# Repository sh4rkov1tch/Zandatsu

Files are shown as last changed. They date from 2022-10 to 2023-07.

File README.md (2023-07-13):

# Zandatsu Fighting Controller v1.3

# Introduction
As my first electronics project and as a fighting game player, I've decided to build this controller.
It's a small Mixbox-style controller running with an RP2040-Zero and GP2040CE at its core.
It is using MX-Style switches and Kailh hotswap sockets.

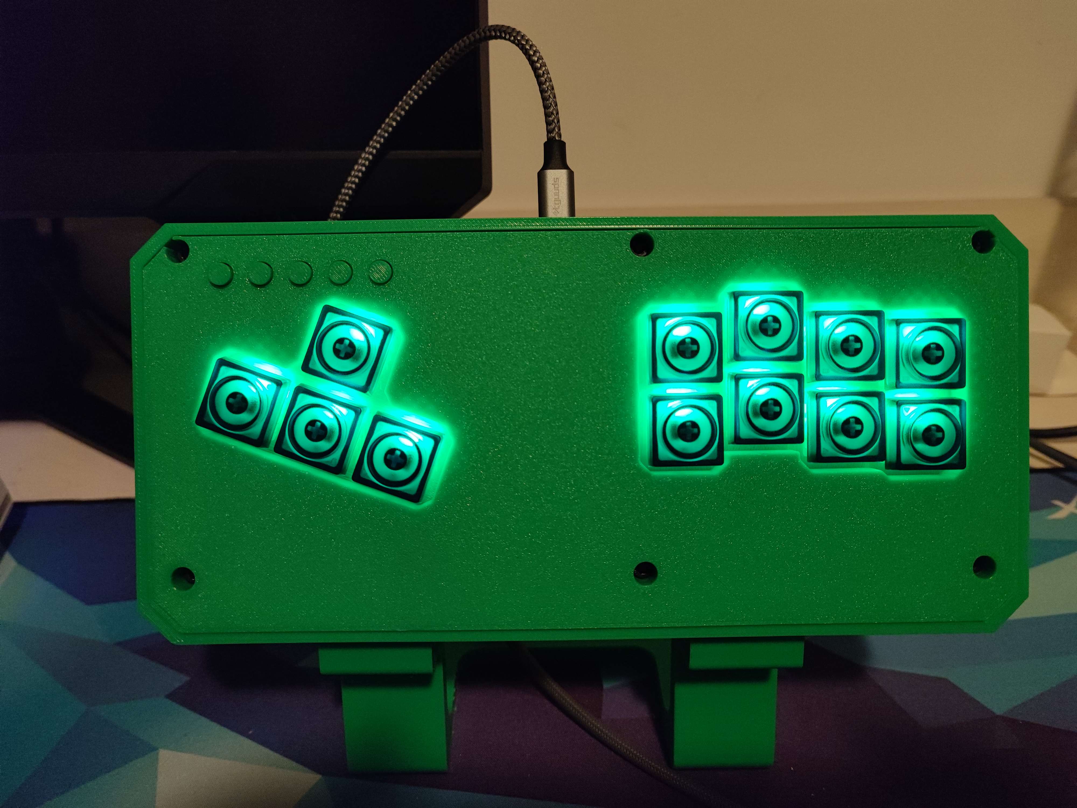
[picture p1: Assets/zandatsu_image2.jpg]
Preview


# Credits
- FeralAI and sleepunit for the awesome GP2040 firmware and the help they gave me through this project
- My electronics and physics professor
- Guydog because I wouldn't even have known that the OpenStick Discord server and GP2040 existed without him
- The OpenStick Community because they made awesome upgrades to GP2040-CE and they also helped me through this project

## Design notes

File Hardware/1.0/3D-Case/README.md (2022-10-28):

# 3D Case
The case was made using OpenSCAD, but I'll also provide the STL files in case you want to print the case only.

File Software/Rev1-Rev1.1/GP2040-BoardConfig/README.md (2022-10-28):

# GP2040 Configuration for Zandatsu
So here's the Zandatsu's boardconfig

## Button Mapping

| Button 	| Pin 	|
|---	|-----	|
| Up 	| 2 	|
| Down 	| 3 	|
| Left 	| 4 	|
| Right  	| 5 	|
| B3 	| 6 	|
| B4 	| 7 	|
| R2 	| 8 	|
| L2 	| 9 	|
| B1 	| 10  	|
| B2 	| 11  	|
| R1 	| 12  	|
| L1 	| 13  	|
| S1 	| 17  	|
| S2 	| 20  	|
| A1 	| 16  	|

## LED Settings
LED Pin - `0`
Max Brightness - `100`
LED Layout  - `WASD`
Brightness Steps - `5`
LEDs per Button - `1`

## LED Order

(From left to right)

```
Up > Down > Left > Right > L1 > R1 > B2 > B1 > B3 > B4 > R2 > L2
```

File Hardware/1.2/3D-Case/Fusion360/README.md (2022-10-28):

# Fusion 360 case
This one is better visually and thinner than the older one, and the screws aren't going to be visible because they're now on the back

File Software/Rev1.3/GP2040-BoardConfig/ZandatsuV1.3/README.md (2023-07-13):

## Zandatsu Rev 1.3 Pin Mappings

## Buttons

| Button | Pin |
|---|-----|
| Up |  1  |
|  Down  |  2  |
|  Left  |  3  |
| Right  |  4  |
|  B1/A/Cross | 5 |
|  B2/B/Circle | 6  |
|  R2/RT | 7  |
|  L2/LT  | 8 |
|  B3/X/Square | 9 |
|  B4/Y/Triangle | 10 |
|  R1/RB | 11 |
|  L1/LB | 15 |
| S1/Back/Select  | 13  |
| S2/Start  | 14 |
| A1/Guide/Home| 12 |
| L3/LS | 27 |
| R3/RS | 26 |

## LEDs

LED Pin: 0

|Index|LED|
|-----|---|
|0|Up|
|1|Left|
|2|Down|
|3|Right|
|4|B1|
|5|B2|
|6|R2|
|7|L2|
|8|B3|
|9|B4|
|10|R1|
|11|L1|

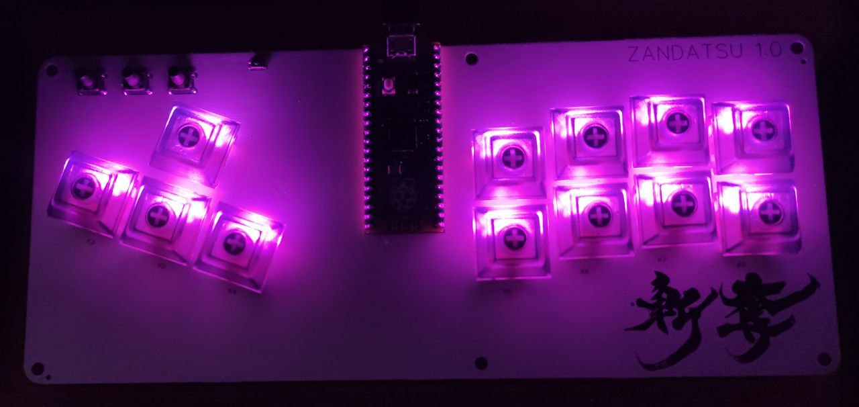
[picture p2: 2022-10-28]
Assets/zandatsu_board.jpg

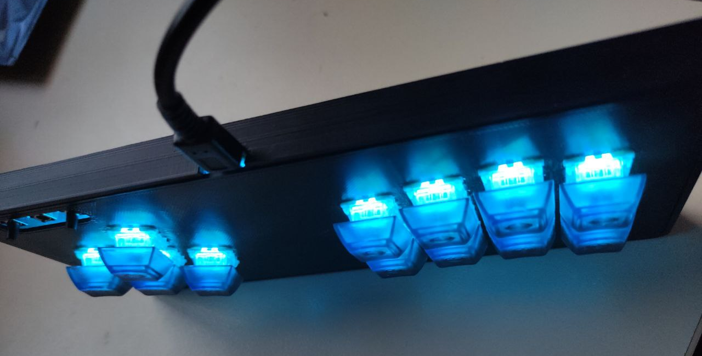
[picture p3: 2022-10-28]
Assets/zandatsu_image1.png

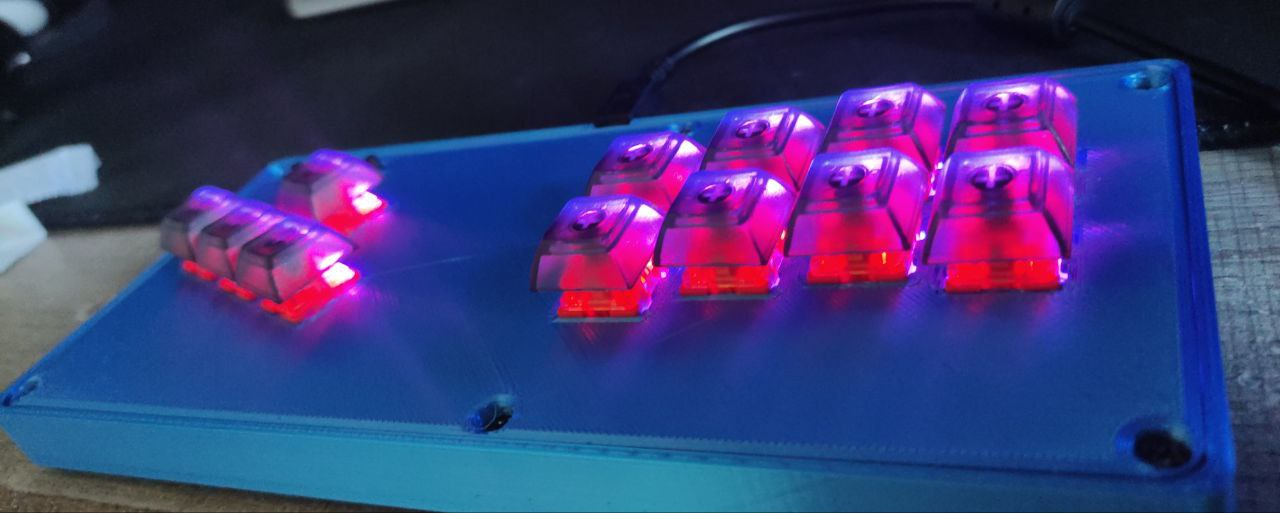
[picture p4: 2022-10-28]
Assets/zandatsu_image0.png

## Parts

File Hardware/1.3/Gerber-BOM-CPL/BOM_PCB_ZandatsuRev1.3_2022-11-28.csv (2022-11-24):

ID | Name | Designator | Footprint | Quantity | Manufacturer Part | Manufacturer | Supplier | Supplier Part | Price
1 | NEOPIXEL_SK6812MINI-E | LED1,LED2,LED3,LED4,LED5,LED6,LED7,LED8,LED9,LED10,LED11,LED12 | SK6812MINI-E_REVERSE-MOUNT | 12 | SK6812MINI-E | null | LCSC | C9900001298
2 | RP2040-Zero | U1 | RP2040-ZERO_SMD_MULTILAYER | 1 |  | Waveshare
3 | TS-1095-A14B3-D1 | SW1,SW2,SW3,SW4,SW5 | SW-TH_4P-L6.0-W6.0-P4.50-LS6.5 | 5 | TS-1095-A14B3-D1 | Yuandi | LCSC | C493021 | 0.045
4 | MXONLY-1U-HOTSWAP | K1,K2,K3,K4,K5,K6,K7,K8,K9,K10,K11,K12 | MXONLY-1U-HOTSWAP | 12

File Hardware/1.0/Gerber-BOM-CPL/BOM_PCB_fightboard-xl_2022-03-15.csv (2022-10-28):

ID | Name | Designator | Footprint | Quantity | Manufacturer Part | Manufacturer | Supplier | Supplier Part | Price
1 | MXONLY-1U-HOTSWAP | K1,K2,K3,K4,K5,K6,K7,K8,K9,K10,K11,K12 | MXONLY-1U-HOTSWAP | 12
2 | TSA061G90-250 | SW13,SW14,SW15 | SW-TH_4P-L6.0-W6.0-P4.50-LS6.5 | 3 | TSA061G90-250 | BRIGHT | LCSC | C294505 | 0.023
3 | TS-1185EC-C-D-B | SW17 | SW-SMD_4P-L3.7-W3.0-P1.50-LS4.7 | 1 | TS-1185EC-C-D-B | XKB Enterprise | LCSC | C318893 | 0.055
4 | RASPBERRY Pi Pico Through Holes | U4 | RASPBERRY PI PICO | 1
5 | WS2812B-2020 | LED1,LED2,LED3,LED4,LED5,LED6,LED7,LED8,LED9,LED10,LED11,LED12 | LED-SMD_4P-L2.0-W2.0-TL_WS2812B-2020 | 12 | WS2812B-2020 | Worldsemi | LCSC | C965555 | 0.156

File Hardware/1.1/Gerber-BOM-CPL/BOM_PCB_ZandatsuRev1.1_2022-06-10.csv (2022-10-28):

ID | Name | Designator | Footprint | Quantity | Manufacturer Part | Manufacturer | Supplier | Supplier Part | Price
1 | RASPBERRY-PI-PICO_TH/SMT (No Debug Pins) | 1 | RASPBERRY-PI-PICO | 1 |  | Raspberry Pi Foundation | Raspberry Pi | RP2040
2 | MXONLY-1U-HOTSWAP | K1,K2,K3,K4,K5,K6,K7,K8,K9,K10,K11,K12 | MXONLY-1U-HOTSWAP | 12
3 | WS2812B-2020 | LED1,LED2,LED3,LED4,LED5,LED6,LED7,LED8,LED9,LED10,LED11,LED12 | LED-SMD_4P-L2.0-W2.0-TL_WS2812B-2020 | 12 | WS2812B-2020 | Worldsemi | LCSC | C965555 | 0.11
4 | TSA061G90-250 | SW13,SW14,SW15 | SW-TH_4P-L6.0-W6.0-P4.50-LS6.5 | 3 | TSA061G90-250 | BRIGHT | LCSC | C294505 | 0.024
5 | TS-1185EC-C-D-B | SW17 | SW-SMD_4P-L3.7-W3.0-P1.50-LS4.7 | 1 | TS-1185EC-C-D-B | XKB Enterprise | LCSC | C318893 | 0.054

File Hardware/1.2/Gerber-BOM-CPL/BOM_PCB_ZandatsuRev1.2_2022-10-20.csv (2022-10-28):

ID | Name | Designator | Footprint | Quantity | Manufacturer Part | Manufacturer | Supplier | Supplier Part | Price
1 | TC-1101DR-9.0H-160 | SW1,SW2,SW3,SW4,SW5 | SW-TH_4P-L6.0-W6.0-P4.50-LS6.5 | 5 | TC-1101DR-9.0H-160 | DEALON(德艺隆) | LCSC | C2905145 | 0.029
2 | RP2040-Zero | U1 | RP2040-ZERO | 1 |  | Waveshare
3 | MXONLY-1U-HOTSWAP | K1,K2,K3,K4,K5,K6,K7,K8,K9,K10,K11,K12 | MXONLY-1U-HOTSWAP | 12
4 | WS2812B-2020 | LED1,LED2,LED3,LED4,LED5,LED6,LED7,LED8,LED9,LED10,LED11,LED12 | LED-SMD_4P-L2.0-W2.0-TL_WS2812B-2020 | 12 | WS2812B-2020 | Worldsemi | LCSC | C965555 | 0.11

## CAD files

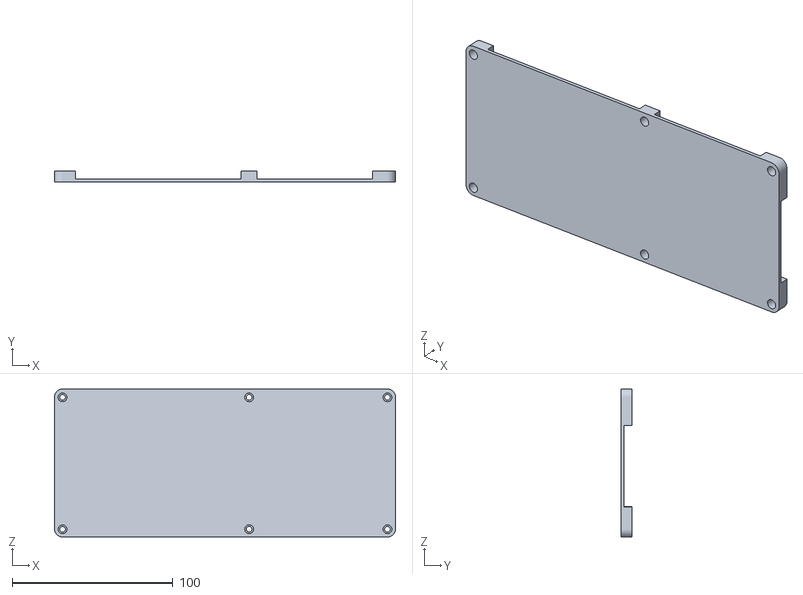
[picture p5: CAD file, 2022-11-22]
Hardware/1.2/3D-Case/Fusion360/zandatsu_back_plate.stl
212.0 x 7.00 x 92.0

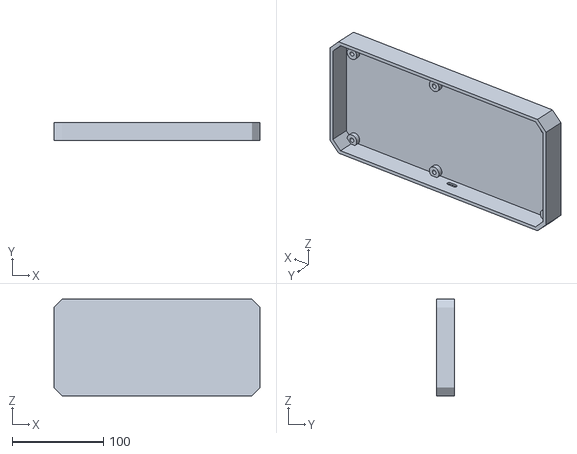
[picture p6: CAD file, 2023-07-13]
Hardware/1.3/3D-Case/STL_Files/case_base.stl
226.0 x 20.0 x 106.0

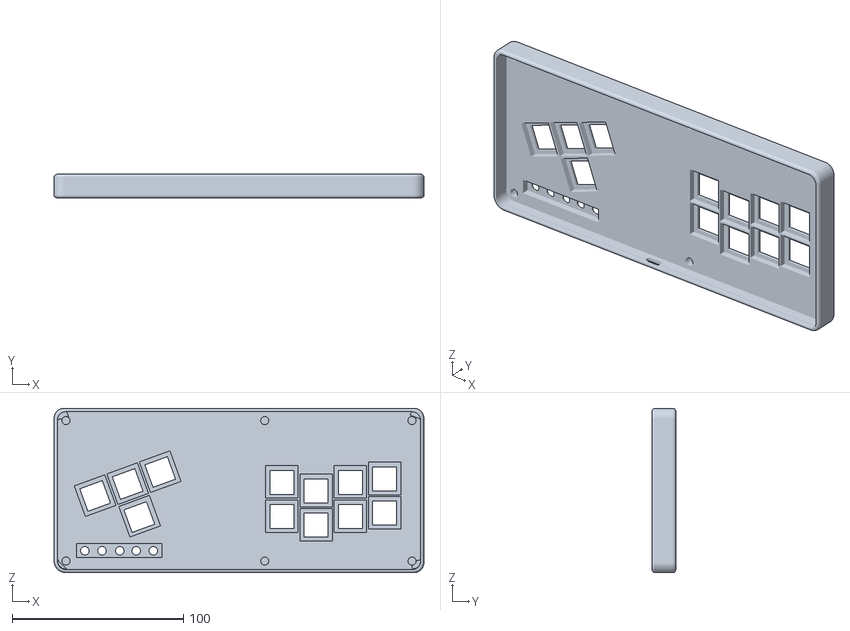
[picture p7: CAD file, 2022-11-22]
Hardware/1.2/3D-Case/Fusion360/zandatsu_front_case.stl
216.0 x 13.8 x 96.0

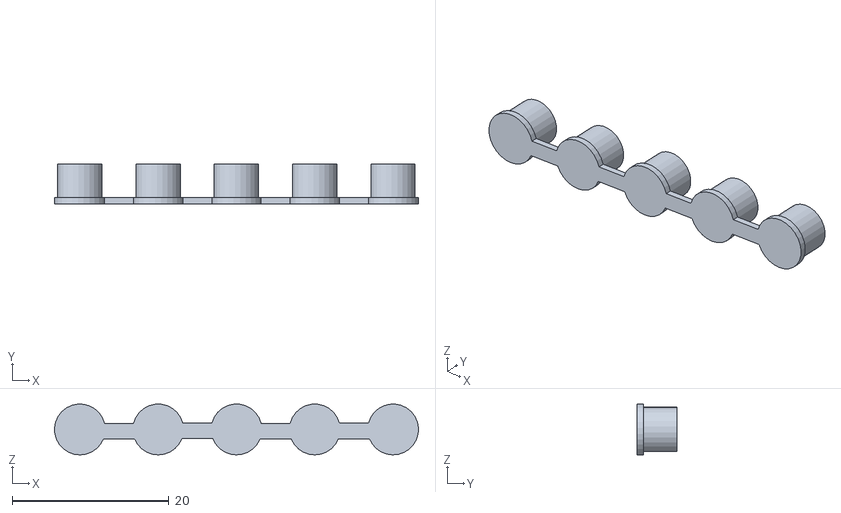
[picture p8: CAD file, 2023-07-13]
Hardware/1.3/3D-Case/STL_Files/buttons.stl
46.5 x 5.10 x 6.49

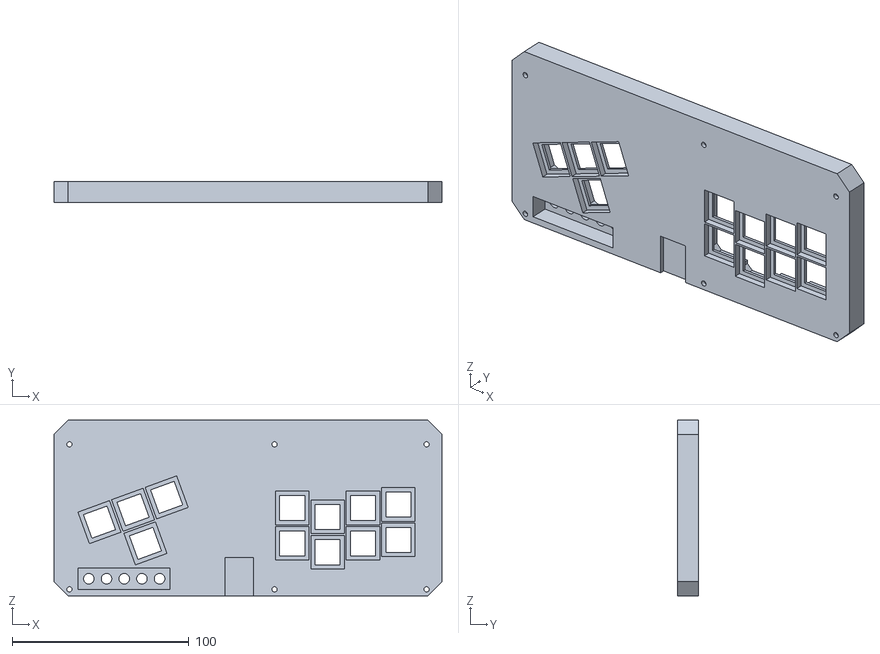
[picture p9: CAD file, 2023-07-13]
Hardware/1.3/3D-Case/STL_Files/frontcase.stl
219.4 x 12.2 x 99.4

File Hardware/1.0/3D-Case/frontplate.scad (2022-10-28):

$fn=75;
szMechanicalSwitch = 14; //Side size

module switchSlot(arrPos, angle=0){
 szMechanicalSwitch = 14.2;
 tabWidth = szMechanicalSwitch+2;
 tabHeight = 3.5;
 
 for(pos = arrPos){
 translate(pos)
  rotate([90, 0, angle]){
   cube(szMechanicalSwitch, center=true);
   translate([0, -6.1, 0])
      cube(19, center=true);
   translate([0, 0, -4.05])
     cube([tabWidth, tabWidth, tabHeight], center=true);
   translate([0, 0, 4.05])
     cube([tabWidth, tabWidth, tabHeight], center=true);
  }
 }
}

module screwSlot(arrPos, diameter=3, wallthickness=2, height=3){
 for(pos = arrPos){
  translate(pos){
   difference(){
    cylinder(h=height, d=diameter+wallthickness, center=true);
    cylinder(h=height+1, d=diameter, center=true);
   }
  }
 } 
}

arrScrewPos = [
 [120, 4, -1.5],
 [120,86, -1.5],
 [206, 4, -1.5],
 [206,86, -1.5],
 [  4, 4, -1.5],
 [  4,86, -1.5]
];


arrWasdPos = [
 [47, 60, 0],
 [21, 48, 0],
 [40, 41, 0],
 [59, 34, 0]
];

posPico = [101, 64, 0];
szPico = [28, 60, 8.5];

arrBtnPos = [
 [127.4, 33.8, 0],
 [127.4, 53.8, 0],
 [147.4, 58.8, 0],
 [147.4, 38.8, 0],
 [167.4, 61.3, 0],
 [167.4, 41.3, 0],
 [187.4, 58.8, 0],
 [187.4, 38.8, 0],
];

arrSecBtnPos = [
 [15.6, 81.7, 0],
 [28.2, 81.5, 0],
 [40.6, 81.4, 0]
];

szSecondaryButtons = 4.4; //Diameter
angleWasd = -20;

roundedCornerDiam = 10;
arrCompRd = [roundedCornerDiam/2, roundedCornerDiam/2];

arrSzPlate = [210-roundedCornerDiam, 90-roundedCornerDiam, 5];

difference(){
 union(){

  translate([roundedCornerDiam/2, roundedCornerDiam/2, 0])
 minkowski(){
  cylinder(d=roundedCornerDiam, h=0.0001, center=false);
  cube(arrSzPlate);
 }
 
}
 
 switchSlot(arrWasdPos, -20);
 switchSlot(arrBtnPos);

 for(secBtnPos = arrSecBtnPos){
   translate(secBtnPos){
    cylinder(d=szSecondaryButtons, h=arrSzPlate.z*2+1 , center=true);
    cube(8, center=true);
   }
}
 
 for(screwPos = arrScrewPos){
    translate(screwPos){
        cylinder(d=3.1, h=arrSzPlate.z*2, center=true);
    }
    translate(screwPos+[0, 0, 5]){
        cylinder(d=6, h=4, center=true);
    }
}
    translate(posPico)
        cube(szPico, center=true);
    translate([61.44, 86.226, 0.5])
        cube([7, 6, 4], center=true);
}
//screwSlot(arrScrewPos, 2.5, 3.5);

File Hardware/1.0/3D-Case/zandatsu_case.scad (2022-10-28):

$fn=70;

iWallThickness = 2;

arrSzPCB = [210, 90, 1.6];
arrBackplaneDiffXY = [iWallThickness*2+1, iWallThickness*2+1, 0];
arrErrorMargin = [1, 1, 1];

iRoundedCornerDiam = 10;
arrRoundedCornerOffset = [iRoundedCornerDiam, iRoundedCornerDiam, 0];

iHeightPylone = 3;
iDiamPylone = 6;
iBackplaneThickness = 3;
iCaseThickness = iBackplaneThickness + 1.6 + 3 +3.6;
arrSzCase = arrSzPCB+arrBackplaneDiffXY-arrRoundedCornerOffset+[0, 0, iCaseThickness];
arrSzHole = arrSzPCB-arrRoundedCornerOffset+arrErrorMargin+[0, 0, iCaseThickness-iBackplaneThickness+0.1];

iUSBHeight = iHeightPylone+1.6+0.5+iBackplaneThickness;
arrUSBSize= [14, 20, 6];


arrScrewPos = [
 [120, 4, -1.5],
 [120,86, -1.5],
 [206, 4, -1.5],
 [206,86, -1.5],
 [  4, 4, -1.5],
 [  4,86, -1.5]
];

arrUSBPos = [arrScrewPos[0].x-19+3, 99,  iUSBHeight];

translate(arrRoundedCornerOffset)
    difference(){
        difference(){
            minkowski(){
             cube(arrSzCase);
             cylinder(h=0.000000001, d=iRoundedCornerDiam);
            }
            translate([0, 0, iBackplaneThickness]+arrBackplaneDiffXY/2-arrErrorMargin/2)
                minkowski(){
                    cube(arrSzHole);
                    cylinder(h=0.000001, d=iRoundedCornerDiam);
                }
        translate(arrUSBPos-arrBackplaneDiffXY+[0, 0, 3])
            cube(arrUSBSize, center=true);
    }
}



for(screwPos = arrScrewPos){
   difference(){
       translate(arrRoundedCornerOffset/2+arrBackplaneDiffXY/2+[0, 0, iBackplaneThickness-0.2]+screwPos+[0, 0, 3])
        minkowski(){
        cylinder(h=iHeightPylone, d=iDiamPylone, center=true);
        cube([iDiamPylone/1.3, iDiamPylone/1.3, 0.01], center=true);
        }
       translate(arrRoundedCornerOffset/2+arrBackplaneDiffXY/2+[0, 0, iBackplaneThickness-0.2]+screwPos+[0, 0, 3])
        cylinder(h=iHeightPylone+0.1, d=iDiamPylone/1.6, center=true);
    }
}

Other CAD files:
Hardware/1.1/3D-Case/frontplate.scad
Hardware/1.2/3D-Case/OpenSCAD/frontplate.scad
Hardware/1.2/3D-Case/OpenSCAD/zandatsu_case.scad
Hardware/1.3/3D-Case/F360_Project/ZandatsuCase_Angular.f3z

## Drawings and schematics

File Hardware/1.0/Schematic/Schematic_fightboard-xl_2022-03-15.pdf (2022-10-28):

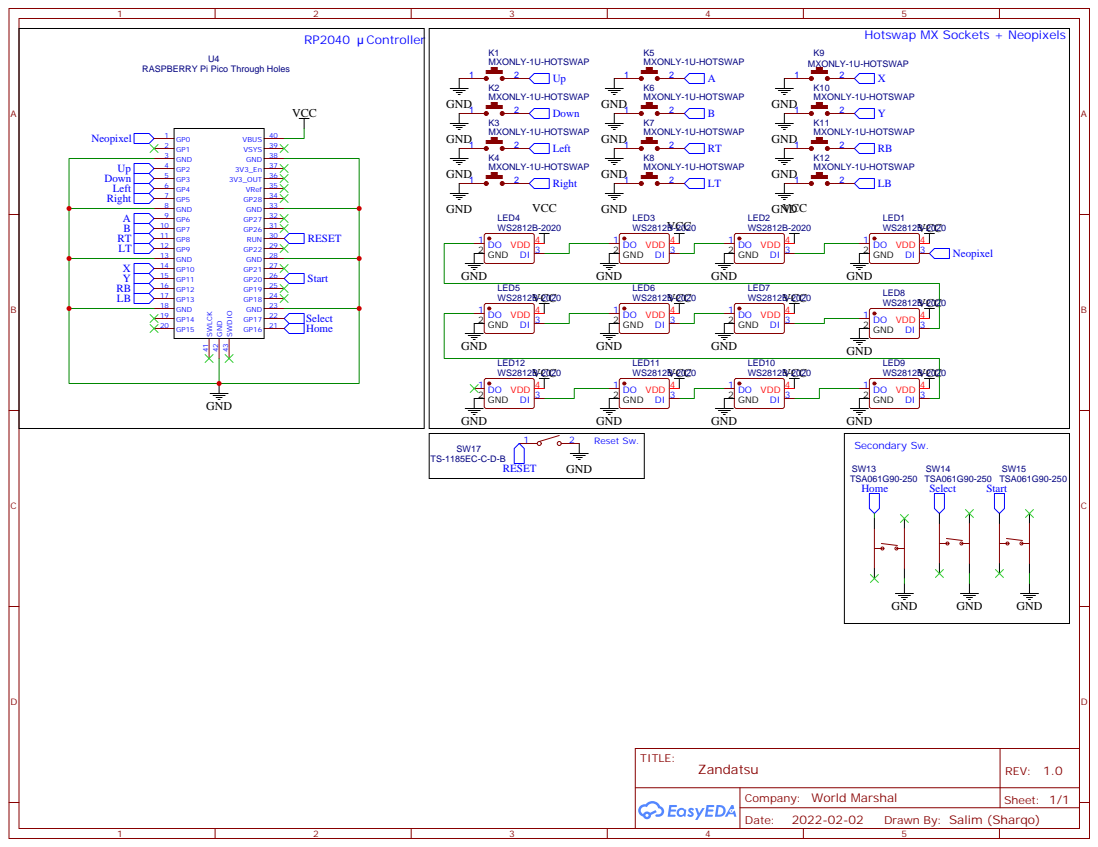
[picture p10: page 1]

RASPBERRY Pi Pico Through Holes

Drawn By: Salim (Sharqo)

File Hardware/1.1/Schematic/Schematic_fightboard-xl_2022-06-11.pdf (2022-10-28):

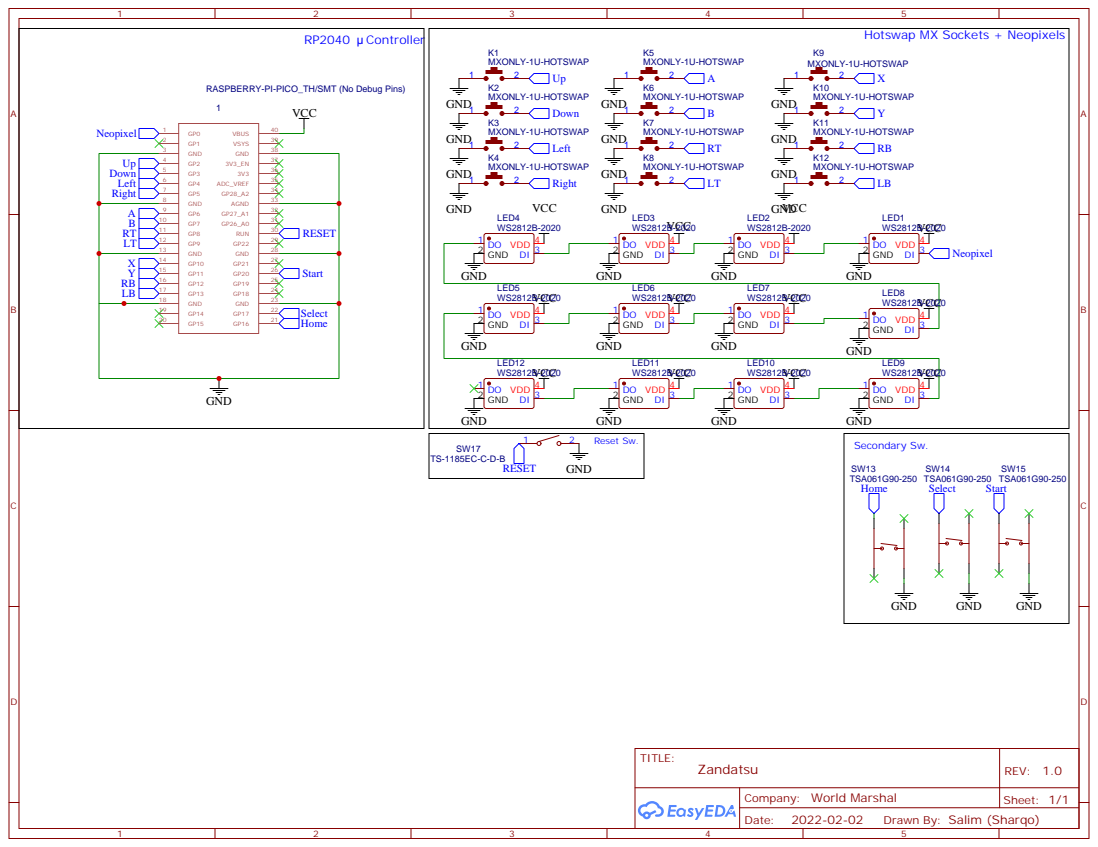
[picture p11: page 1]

RASPBERRY-PI-PICO_TH/SMT (No Debug Pins)

Drawn By: Salim (Sharqo)

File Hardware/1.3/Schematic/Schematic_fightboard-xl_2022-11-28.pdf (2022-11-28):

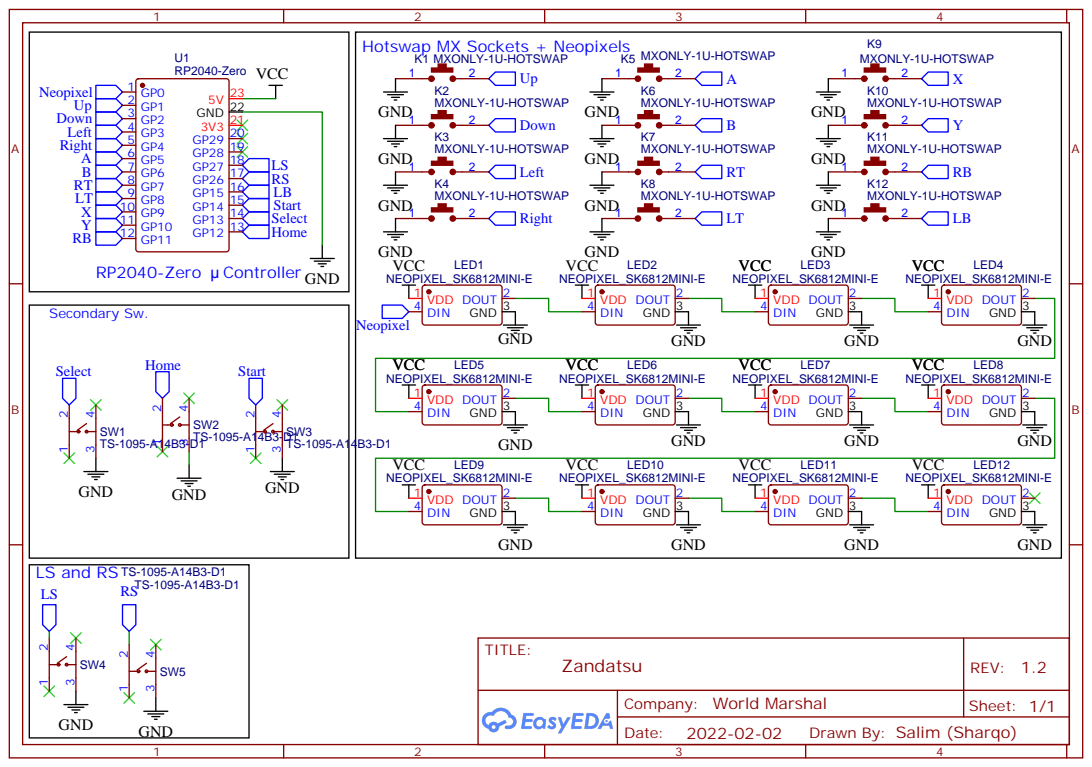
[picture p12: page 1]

Drawn By: Salim (Sharqo)

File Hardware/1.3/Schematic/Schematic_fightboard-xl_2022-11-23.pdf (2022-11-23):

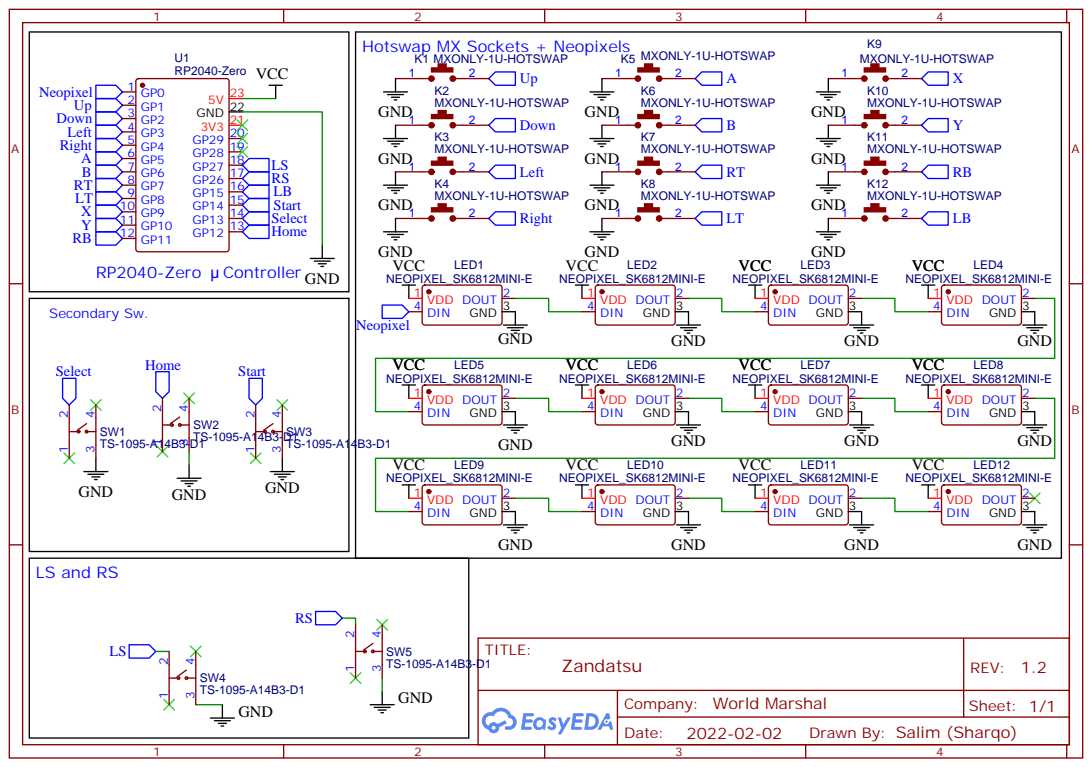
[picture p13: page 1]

Drawn By: Salim (Sharqo)

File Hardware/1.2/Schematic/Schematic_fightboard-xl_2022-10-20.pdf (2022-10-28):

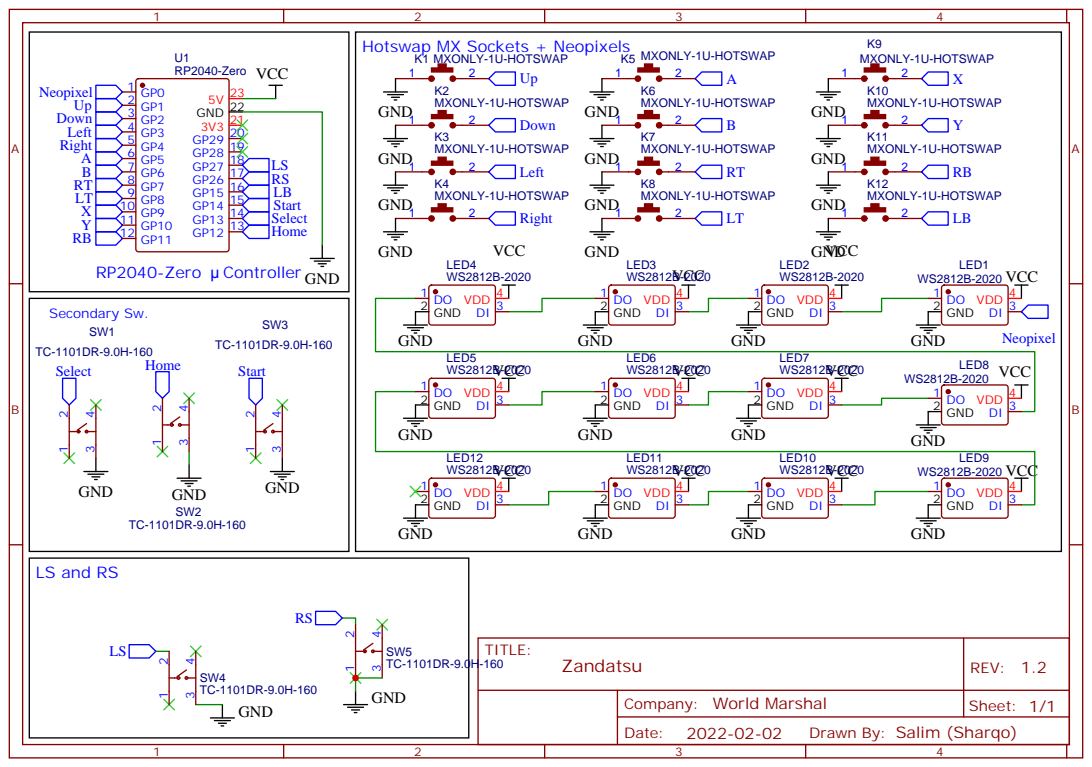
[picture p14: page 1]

Drawn By: Salim (Sharqo)

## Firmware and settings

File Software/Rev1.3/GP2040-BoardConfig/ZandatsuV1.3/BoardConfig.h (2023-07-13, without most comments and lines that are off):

#define PICO_BOARD_CONFIG_H_
#include "enums.pb.h"
#define PIN_DPAD_UP     1           // UP
#define PIN_DPAD_DOWN   2           // DOWN
#define PIN_DPAD_LEFT   3           // LEFT
#define PIN_DPAD_RIGHT  4           // RIGHT
#define PIN_BUTTON_B1   5           // B1 / A / B / Cross / 2 / K1
#define PIN_BUTTON_B2   6           // B2 / B / A / Circle / 3 / K2
#define PIN_BUTTON_R2   7           // R2 / RT / ZR / R2 / 8 / K3
#define PIN_BUTTON_L2   8           // L2 / LT / ZL / L2 / 7 / K4
#define PIN_BUTTON_B3   9          // B3 / X / Y / Square / 1 / P1
#define PIN_BUTTON_B4   10          // B4 / Y / X / Triangle / 4 / P2
#define PIN_BUTTON_R1   11          // R1 / RB / R / R1 / 6 / P3
#define PIN_BUTTON_L1   15          // L1 / LB / L / L1 / 5 / P4
#define PIN_BUTTON_S1   13          // S1 / Back / Minus / Select / 9 / Coin
#define PIN_BUTTON_S2   14					// S2 / Start / Plus / Start / 10 / Start
#define PIN_BUTTON_L3   27          // L3 / LS / LS / L3 / 11 / LS
#define PIN_BUTTON_R3   26          // R3 / RS / RS / R3 / 12 / RS
#define PIN_BUTTON_A1   12          // A1 / Guide / Home / PS / 13 / ~
#define PIN_BUTTON_A2   -1          // A2 / ~ / Capture / ~ / 14 / ~
#define PIN_BUTTON_FN   -1          // Hotkey Function
#define PIN_BUTTON_TURBO -1         // Turbo
#define PIN_BUTTON_REVERSE -1       // UDLR Reverse
#define PIN_SLIDER_LS    -1         // Left Stick Slider
#define PIN_SLIDER_RS    -1         // Right Stick Slider
#define PIN_SLIDER_SOCD_ONE    -1         // SOCD Slider Pin One
#define PIN_SLIDER_SOCD_TWO    -1         // SOCD Slider Pin Two
#define DEFAULT_SOCD_MODE SOCD_MODE_NEUTRAL
#define SLIDER_SOCD_SLOT_ONE SOCD_MODE_UP_PRIORITY
#define SLIDER_SOCD_SLOT_TWO  SOCD_MODE_SECOND_INPUT_PRIORITY
#define SLIDER_SOCD_SLOT_DEFAULT SOCD_MODE_NEUTRAL
#define DEFAULT_FORCED_SETUP_MODE FORCED_SETUP_MODE_OFF // 	FORCED_SETUP_MODE_OFF, FORCED_SETUP_MODE_LOCK_MODE_SWITCH, FORCED_SETUP_MODE_LOCK_WEB_CONFIG, FORCED_SETUP_MODE_LOCK_BOTH
#define DEFAULT_LOCK_HOTKEYS false // or true
#define DEFAULT_INPUT_MODE INPUT_MODE_XINPUT //INPUT_MODE_XINPUT (XInput), INPUT_MODE_SWITCH (Nintendo Switch), INPUT_MODE_HID (D-Input), INPUT_MODE_KEYBOARD (Keyboard)
#define DEFAULT_DPAD_MODE DPAD_MODE_DIGITAL  //DPAD_MODE_DIGITAL, DPAD_MODE_LEFT_ANALOG, DPAD_MODE_RIGHT_ANALOG,
#define TURBO_LED_PIN -1
#define BOARD_LEDS_PIN 0
#define LED_BRIGHTNESS_MAXIMUM 100
#define LED_BRIGHTNESS_STEPS 5
#define LED_FORMAT LED_FORMAT_GRB
#define LEDS_PER_PIXEL 1
#define LEDS_DPAD_UP     0
#define LEDS_DPAD_LEFT   1
#define LEDS_DPAD_DOWN	 2
#define LEDS_DPAD_RIGHT  3
#define LEDS_BUTTON_B1   4
#define LEDS_BUTTON_B2   5
#define LEDS_BUTTON_R2	 6
#define LEDS_BUTTON_L2   7
#define LEDS_BUTTON_B3   8
#define LEDS_BUTTON_B4   9
#define LEDS_BUTTON_R1   10
#define LEDS_BUTTON_L1   11
#define PLED_TYPE PLED_TYPE_NONE
#define PLED1_PIN -1
#define PLED2_PIN -1
#define PLED3_PIN -1
#define PLED4_PIN -1
#define ANALOG_ADC_1_VRX -1
#define ANALOG_ADC_1_VRY -1
#define ANALOG_ADC_1_MODE DPAD_MODE_LEFT_ANALOG
#define ANALOG_ADC_1_INVERT INVERT_NONE
#define ANALOG_ADC_2_VRX -1
#define ANALOG_ADC_2_VRY -1
#define ANALOG_ADC_2_MODE DPAD_MODE_RIGHT_ANALOG
#define ANALOG_ADC_2_INVERT INVERT_NONE
#define HAS_I2C_DISPLAY 0
#define I2C_SDA_PIN -1
#define I2C_SCL_PIN -1
#define I2C_BLOCK i2c0
#define I2C_SPEED 400000
#define DISPLAY_FLIP 0
#define DISPLAY_INVERT 0
#define DISPLAY_SAVER_TIMEOUT 0
#define I2C_ANALOG1219_SDA_PIN -1
#define I2C_ANALOG1219_SCL_PIN -1
#define I2C_ANALOG1219_BLOCK i2c0
#define I2C_ANALOG1219_SPEED 400000
#define I2C_ANALOG1219_ADDRESS 0x40
#define REVERSE_LED_PIN -1
#define REVERSE_UP_DEFAULT 1
#define REVERSE_DOWN_DEFAULT 1
#define REVERSE_LEFT_DEFAULT 1
#define REVERSE_RIGHT_DEFAULT 1
#define BUTTON_LAYOUT BUTTON_LAYOUT_KEYBOARD_ANGLED
#define BUTTON_LAYOUT_RIGHT BUTTON_LAYOUT_SEGA2P
#define SPLASH_MODE SPLASH_MODE_NONE
#define SPLASH_CHOICE SPLASH_CHOICE_MAIN
#define SPLASH_DURATION 7500 // Duration in milliseconds
#define BOARD_LED_TYPE ON_BOARD_LED_MODE_OFF
#define PIN_DUAL_DIRECTIONAL_UP -1
#define PIN_DUAL_DIRECTIONAL_DOWN -1
#define PIN_DUAL_DIRECTIONAL_LEFT -1
#define PIN_DUAL_DIRECTIONAL_RIGHT -1
#define DUAL_DIRECTIONAL_STICK_MODE DPAD_MODE_DIGITAL
#define DUAL_DIRECTIONAL_COMBINE_MODE DUAL_COMBINE_MODE_MIXED
#define PIN_TILT_1 -1
#define PIN_TILT_2 -1
#define PIN_TILT_FUNCTION -1
#define PIN_TILT_LEFT_ANALOG_UP -1
#define PIN_TILT_LEFT_ANALOG_DOWN -1
#define PIN_TILT_LEFT_ANALOG_LEFT -1
#define PIN_TILT_LEFT_ANALOG_RIGHT -1
#define PIN_TILT_RIGHT_ANALOG_UP -1
#define PIN_TILT_RIGHT_ANALOG_DOWN -1
#define PIN_TILT_RIGHT_ANALOG_LEFT -1
#define PIN_TILT_RIGHT_ANALOG_RIGHT -1
#define TILT_SOCD_MODE SOCD_MODE_NEUTRAL
#define BOOTSEL_BUTTON_MASK 0 // 0 means none, get other mask from GamepadState.h
#define BUZZER_ENABLED 0
#define BUZZER_PIN -1
#define BUZZER_VOLUME 100
#define EXTRA_BUTTON_MASK 0 // 0 means none, get other mask from GamepadState.h
#define EXTRA_BUTTON_PIN -1
#define FOCUS_MODE_BUTTON_MASK 0 // 0 means none, get other mask from GamepadState.h
#define FOCUS_MODE_PIN -1
#define FOCUS_MODE_OLED_LOCK_ENABLED 0
#define FOCUS_MODE_RGB_LOCK_ENABLED 0
#define FOCUS_MODE_BUTTON_LOCK_ENABLED 0
#define KEY_DPAD_UP     HID_KEY_ARROW_UP      // UP
#define KEY_DPAD_DOWN   HID_KEY_ARROW_DOWN    // DOWN
#define KEY_DPAD_RIGHT  HID_KEY_ARROW_RIGHT   // RIGHT
#define KEY_DPAD_LEFT   HID_KEY_ARROW_LEFT    // LEFT
#define KEY_BUTTON_B1   HID_KEY_SHIFT_LEFT    // B1 / A / B / Cross / 2 / K1
#define KEY_BUTTON_B2   HID_KEY_Z             // B2 / B / A / Circle / 3 / K2
#define KEY_BUTTON_R2   HID_KEY_X             // R2 / RT / ZR / R2 / 8 / K3
#define KEY_BUTTON_L2   HID_KEY_V             // L2 / LT / ZL / L2 / 7 / K4
#define KEY_BUTTON_B3   HID_KEY_CONTROL_LEFT  // B3 / X / Y / Square / 1 / P1
#define KEY_BUTTON_B4   HID_KEY_ALT_LEFT      // B4 / Y / X / Triangle / 4 / P2
#define KEY_BUTTON_R1   HID_KEY_SPACE         // R1 / RB / R / R1 / 6 / P3
#define KEY_BUTTON_L1   HID_KEY_C             // L1 / LB / L / L1 / 5 / P4
#define KEY_BUTTON_S1   HID_KEY_5             // S1 / Back / Minus / Select / 9 / Coin
#define KEY_BUTTON_S2   HID_KEY_1             // S2 / Start / Plus / Start / 10 / Start
#define KEY_BUTTON_L3   HID_KEY_EQUAL         // L3 / LS / LS / L3 / 11 / LS
#define KEY_BUTTON_R3   HID_KEY_MINUS         // R3 / RS / RS / R3 / 12 / RS
#define KEY_BUTTON_A1   HID_KEY_9             // A1 / Guide / Home / PS / 13 / ~
#define KEY_BUTTON_A2   HID_KEY_F2            // A2 / ~ / Capture / ~ / 14 / ~
#define KEYBOARD_HOST_ENABLED 0
#define KEYBOARD_HOST_PIN_DPLUS -1
#define DEFAULT_SPLASH \
    0x00,0x00,0x00,0x00,0x00,0x00,0x00,0x00,0x00,0x00,0x00,0x00,0x00,0x00,0x00,0x00, \
	0x00,0x00,0x00,0x00,0x00,0x00,0x00,0x00,0x00,0x00,0x00,0x00,0x00,0x00,0x00,0x00, \
	0x00,0x00,0x00,0x00,0x00,0x00,0x00,0x00,0x00,0x00,0x00,0x00,0x00,0x00,0x00,0x00, \
	0x00,0x00,0x00,0x00,0x00,0x00,0x00,0x00,0x00,0x00,0x00,0x00,0x00,0x00,0x00,0x00, \
	0x00,0x00,0x00,0x00,0x00,0x00,0x00,0x00,0x00,0x00,0x00,0x00,0x00,0x00,0x00,0x00, \
	0x00,0x00,0x00,0x00,0x00,0x00,0x00,0x00,0x00,0x00,0x00,0x00,0x00,0x00,0x00,0x00, \
	0x00,0x00,0x00,0x00,0x00,0x00,0x00,0x00,0x00,0x00,0x00,0x00,0x00,0x00,0x00,0x00, \
	0x00,0x00,0x00,0x00,0x00,0x00,0x00,0x00,0x00,0x00,0x00,0x00,0x00,0x00,0x00,0x00, \
	0x00,0x00,0x00,0x00,0x00,0x00,0x00,0x00,0x00,0x00,0x00,0x00,0x00,0x00,0x00,0x00, \
	0x00,0x00,0x00,0x00,0x00,0x00,0x00,0x00,0x00,0x00,0x00,0x00,0x00,0x00,0x00,0x00, \
	0x00,0x00,0x00,0x00,0x00,0x00,0x00,0x00,0x00,0x00,0x00,0x00,0x00,0x00,0x00,0x00, \
	0x00,0x00,0x00,0x00,0x00,0x00,0x00,0x00,0x00,0x00,0x00,0x00,0x00,0x00,0x00,0x00, \
	0x00,0x00,0x00,0x00,0x00,0x00,0x00,0x00,0x00,0x00,0x00,0x00,0x00,0x00,0x00,0x00, \
	0x00,0x00,0x00,0x00,0x00,0x00,0x00,0x00,0x00,0x00,0x00,0x00,0x00,0x00,0x00,0x00, \
	0x00,0x00,0x00,0x00,0x00,0x00,0x00,0x00,0x00,0x00,0x00,0x00,0x00,0x00,0x00,0x00, \
	0x00,0x00,0x00,0x00,0x00,0x00,0x00,0x00,0x00,0x00,0x00,0x00,0x00,0x00,0x00,0x00, \
	0x00,0x00,0x00,0x00,0x00,0x00,0x00,0x00,0x00,0x00,0x00,0x00,0x00,0x20,0x00,0x00, \
	0x00,0x00,0x00,0x00,0x00,0x00,0x00,0x00,0x00,0x00,0x00,0x00,0x00,0x40,0x80,0x00, \
	0x00,0x00,0x00,0x00,0x00,0x00,0x00,0x00,0x00,0x00,0x00,0x00,0x00,0xE0,0xDF,0xC0, \
	0x00,0x00,0x00,0x00,0x00,0x00,0x00,0x00,0x00,0x00,0x00,0x00,0x02,0xC1,0xFF,0xA0, \
	0x00,0x00,0x00,0x00,0x00,0x00,0x00,0x00,0x00,0x00,0x00,0x00,0x1F,0xCF,0xFE,0x80, \
	0x00,0x00,0x00,0x00,0x00,0x00,0x00,0x00,0x00,0x00,0x00,0x00,0x3F,0xFF,0xE0,0x00, \
	0x00,0x00,0x00,0x00,0x00,0x00,0x00,0x00,0x00,0x00,0x00,0x00,0x7F,0xAB,0xC0,0x00, \
	0x00,0x00,0x00,0x00,0x00,0x00,0x00,0x00,0x00,0x2C,0x00,0x00,0xFB,0x83,0xFF,0x00, \
	0x00,0x00,0x00,0x00,0x00,0x00,0x00,0x0C,0x01,0xFF,0x00,0x01,0xF3,0x07,0xFC,0x00, \
	0x00,0x00,0x00,0x00,0x00,0x00,0x00,0x1C,0x07,0xFF,0x00,0x03,0xE0,0x3F,0xF4,0x00, \
	0x00,0x00,0x00,0x00,0x00,0x00,0x2C,0x38,0x0A,0xE7,0x80,0x03,0xC0,0x5F,0x80,0x00, \
	0x00,0x00,0x00,0x20,0x07,0x81,0xFF,0x39,0xC3,0xC7,0x01,0xD7,0x80,0x3F,0x00,0x00, \
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

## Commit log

2022-11-22 Small adjustments
    Couldn't screw the case otherwise
    [zandatsu_back_plate.stl, zandatsu_front_case.stl]
2022-11-23 New Revision! Fixes a few things
    [BOM_PCB_ZandatsuRev1.3_2022-11-23.csv, PickAndPlace_PCB_ZandatsuRev1.3_2022-11-23.csv]
2022-11-23 Added the case, it's slimmer !
    [Zandatsu_1.3_Backplate.stl, Zandatsu_1.3_FrontCase.stl]
2022-11-23 Fixed huge issue on PCB
    [BOM_PCB_ZandatsuRev1.3_2022-11-23.csv, PickAndPlace_PCB_ZandatsuRev1.3_2022-11-23.csv]
2022-11-24 Fixed huge oopsie in footprints
    [BOM_PCB_ZandatsuRev1.3_2022-11-24.csv, PickAndPlace_PCB_ZandatsuRev1.3_2022-11-24.csv]
2022-11-24 Fixed SK6812Mini-E footprint yet again
    [BOM_PCB_ZandatsuRev1.3_2022-11-24.csv, PickAndPlace_PCB_ZandatsuRev1.3_2022-11-24.csv]
2022-11-28 Changed the LED footprint because the previous one was too big
    [BOM_PCB_ZandatsuRev1.3_2022-11-28.csv, PickAndPlace_PCB_ZandatsuRev1.3_2022-11-28.csv]
2022-12-23 Fixed firmware for 1.3, everything works now
    [BoardConfig.h]
2023-01-10 Fixed case
    [Zandatsu_1.3_Backplate.stl, Zandatsu_1.3_FrontCase.stl]
2023-01-11 Fixed case, again
    it was fucked
    [Zandatsu_1.3_Backplate.stl, Zandatsu_1.3_FrontCase.stl]
2023-01-12 Remodeled the case
    [Zandatsu_1.3_Backplate.stl, Zandatsu_1.3_FrontCase.stl]
2023-01-12 Fixed a few things
    [Zandatsu_1.3_Backplate.stl, Zandatsu_1.3_FrontCase.stl]
2023-01-18 Fixed oopsies
    [Zandatsu_1.3_FrontCase.stl]
2023-02-27 Updated firmware and boardconfig for the latest cmake builds of GP2040
2023-07-13 Big design upgrade and firmware update
    [ZandatsuCase_Angular.f3z, Zandatsu_1.3_Backplate.stl, Zandatsu_1.3_FrontCase.stl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]

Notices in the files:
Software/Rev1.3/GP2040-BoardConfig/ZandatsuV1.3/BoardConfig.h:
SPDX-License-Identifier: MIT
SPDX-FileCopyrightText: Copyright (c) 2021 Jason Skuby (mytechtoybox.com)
